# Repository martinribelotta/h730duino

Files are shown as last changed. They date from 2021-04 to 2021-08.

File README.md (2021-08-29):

# H730/733 Duino

Arduino form factor and software compatible board with giant cortex-m7 at 550MHz.

See test firmware [here](https://github.com/martinribelotta/h730duino-firmware)

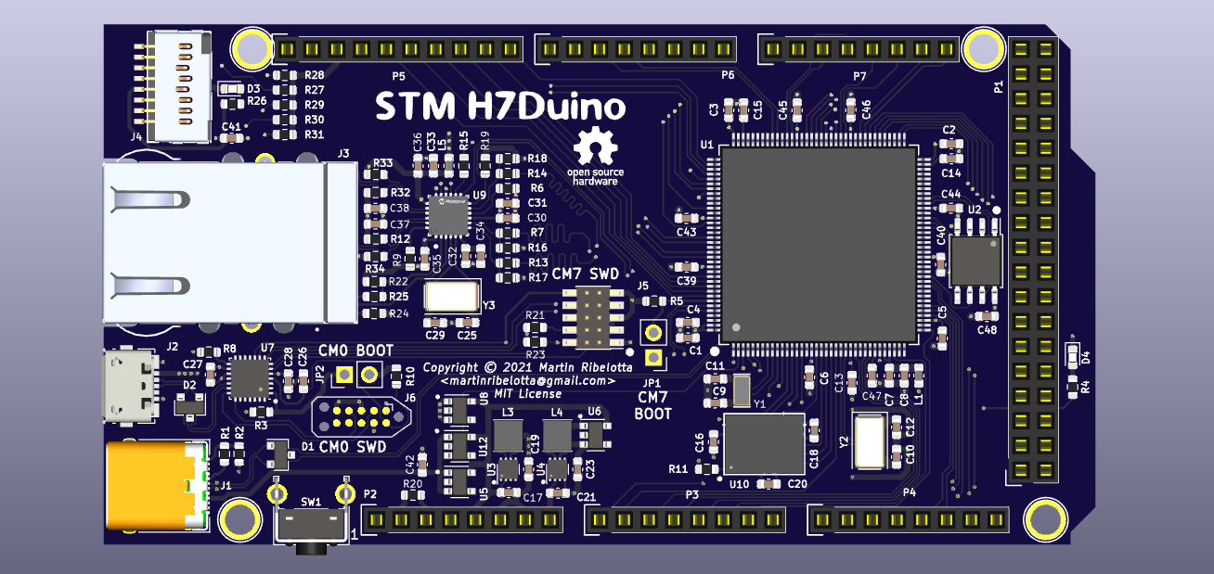
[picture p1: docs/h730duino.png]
banner


## Characteristics

- CPU Cortex-M7 at 550MHz.
- 128K/1 MB of internal flash (depending on the MCU version).
- 500 KB of internal RAM.
- 8 MB of external QSPI PSRAM at 133MHz SDR.
- 16/32/128 MB of external QSPI Flash at 133MHz SDR.
- 10/100Mb Ethernet.
- USB 2.0 OTG Type-C with power switch control.
- USB CMSIS-DAP Debugger.
- micro SD Card slot.
- Arduino Due/Mega compatible pin headers (3.3V IO, 5V tolerant on some pins).
- Arduino API compatible (via STM32Duino project).
- Micropython support.
- Protected power inputs with ideal diodes and DC-DC converter

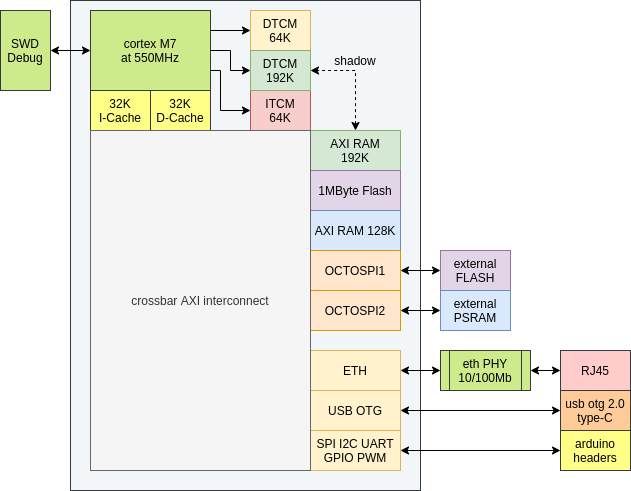
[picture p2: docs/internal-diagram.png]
internal diagram


## Capabilities and applications

Some interesting CPU capabilities are listed below:

- Hard real time capable CPU with predictable execution using tightly coupled memory for instruction and data.
- High speed and precision PWM suitable for motor control (BLDC, Stepper, DC).
- High resolution timing measure in capture mode for some pins.
- Arbitrary waveform generation in any GPIO using DMA without CPU intervention.
- High speed DACs suitable to generate analog signals up to 18MHz.
- Tow high speed 12 bits ADC suitable to capture up to 5MSPS in any channel.
- One high speed 16 bits ADC suitable to capture up to 7.5MSPSP
- Internal RAM with multiple block partitions enabling multiple peripheral access at same time without contention.
- External high density RAM up to 8 MB connected across 133MHz QSPI bus accessible in memory mapped mode or block device mode with on the fly encryption/decryption.
- External high density FLASH up to 16 MB connected across 133MHz QSPI bus accessible in memory mapped mode or block device mode with on the fly encryption/decryption.
- Multiplexed parallel memory controller for LCD and TFT access
- LCD interface with 666, 565 and 888 RGB with hsync/vsync and pixel clk (max 150MHz)
- Parallel capture port at 110MHz
- Parallel signal generation at 50MHz

These capabilities enable multiple interesting applications:

- High precision CNC and 3D printing.
- Signal generator and data acquisition system
- Human machine interface enabled terminal with USB, CAN and Ethernet support
- High speed logic analyzer.
- Programmable instrumentation system.
- Network laboratory instrument.

## Layout

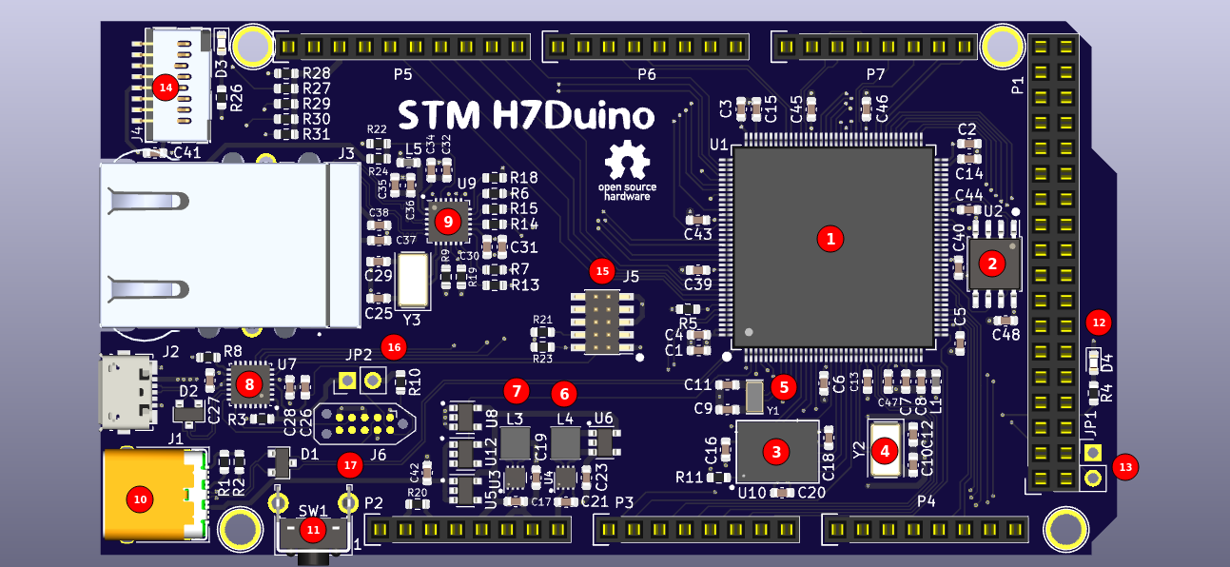
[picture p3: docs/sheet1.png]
layout


 1. MCU STM32H730/733/732
 2. QSPI flash (4/8/16/32MiB)
 3. HyperRAM (8MiB)
 4. 8MHz crystal
 5. 32.768KHz RTC crystal
 6. 5V in regulator
 7. 3.3V main regulator
 8. CMSIS-DAP debugger
 9. Ethernet PHY
 10. USB OTG Full Speed (connected to MCU)
 11. Reset button
 12. User LED
 13. STM32H7 BOOT jumper
 14. MicroSD connector
 15. SWD MCU connector
 16. CMSIS-DAP boot jumper
 17. CMSIS-DAP pogo pins for programming

## Schematics

[Download in PDF format](docs/schematic.pdf)

[Octopart BoM](https://octopart.com/bom-tool/nudLZO8C)

[CSV BoM (octpart compatible)](docs/stm32h7duino-v01.csv)






## License

[MIT License](LICENCE.tx)

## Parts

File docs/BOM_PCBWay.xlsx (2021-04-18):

 |  |  | xxxx xxxx xxxxx xxPCS BOM (Sample Bill of Materials)
Item # | *Designator | *Qty | Manufacturer | *Mfg Part # | Description / Value | *Package/Footprint | Type | Your Instructions / Notes
1 | C1 | 1 | Yageo | CC0603KRX5R5BB475 | Multilayer Ceramic Capacitor, CC Series, 4.7 - F, - 10%, X5R, 6.3 V, 0603 [1608 Metric] | SMD 0603 | SMD | Replaceable part number by equivalent
2 | C10,C12 | 2 | Yageo | CC0603CRNPO9BN1R0 | Surface Mount Ceramic Multilayer Capacitor 1pF 0.25pF C0G 50V 0603 Paper T/R | SMD 0603 | SMD | Replaceable part number by equivalent
3 | C13,C34 | 2 | Yageo | CC0603ZRY5V6BB105 | Surface Mount Ceramic Multilayer Capacitor 1uF -20% to 80% Y5V 10V 0603 Paper T/R | SMD 0603 | SMD | Replaceable part number by equivalent
4 | C14,C15,C42 | 3 | Yageo | CC0603ZRY5V6BB225 | Surface Mount Ceramic Multilayer Capacitor 2.2uF -20% to 80% Y5V 10V 0603 Paper T/R | SMD 0603 | SMD | Replaceable part number by equivalent
5 | C17,C21,C30,C36 | 4 | KEMET | C0603C106M8PACTU | Cap Ceramic 10uF 10V X5R 20% SMD 0603 85°C Paper T/R | SMD 0603 | SMD | Replaceable part number by equivalent
6 | C19,C23 | 2 | Murata | GRM187R61A226ME15D | 0603 22 uF 10 V ±20% Tolerance X5R Multilayer Ceramic Capacitor | SMD 0603 | SMD | Replaceable part number by equivalent
7 | C2,C3,C4,C5,C6,C7,C16,C18,C20,C26,C27,C28,C31,C33,C35,C39,C40,C41,C43,C44,C45,C46,C47,C48 | 24 | Yageo | CC0603KRX7R9BB104 | Multilayer Ceramic Capacitor, CC Series, 0.1 - F, - 10%, X7R, 50 V, 0603 [1608 Metric] | SMD 0603 | SMD | Replaceable part number by equivalent
8 | C32 | 1 | AVX | 06035C471KAT2A | 0603 470 pF 50V ±10 % Tolerance X7R Surface Mount Multilayer Ceramic Capacitor | SMD 0603 | SMD | Replaceable part number by equivalent
9 | C37,C38 | 2 | AVX | 06035C223KAT2A | 0603 22nF 50V ±10 % Tolerance X7R Surface Mount Multilayer Ceramic Capacitor | SMD 0603 | SMD | Replaceable part number by equivalent
10 | C8,C9,C11,C25,C29 | 5 | Yageo | CC0603JRNPO9BN100 | Surface Mount Ceramic Multilayer Capacitor 10pF 5% C0G 50V 0603 Paper T/R | SMD 0603 | SMD | Replaceable part number by equivalent
11 | D1,D2 | 2 | Littelfuse | SP0502BAHTG | SP050xBA Series 8.5 V 30 pF Dual Uni-Directional TVS Avalanche Diode - SOT-23-5 | SOT-23-5 | SMD
12 | D3,D4 | 2 | Osram Opto | LS Q976-NR-1 | LED Uni-Color Super Red 645nm 2-Pin Chip 0603(1608Metric) T/R | SMD 0603 | SMD | Replaceable part number by equivalent
13 | J1 | 1 | Amphenol | 12401610E4#2A | Conn USB Type C RCP 24 POS 0.5mm Solder RA SMD 24 Terminal 1 Port Automotive | USB_C_Receptacle_Amphenol_12401610E4-2A | SMD
14 | J2 | 1 | Molex | 47346-0001 | Micro-USB B Receptacle with Flange, Bottom Mount, Surface Mount, Lead-Free | USB_Micro-B_Molex_47346-0001 | SMD
15 | J3 | 1 | Bel Fuse | L834-1G1T-91 | Conn RJ45 F 8 POS 1.02mm Solder RA Through Hole 16 Terminal 1 Port Tray | RJ45 BEL_L834-1G1T-91 | Thru-home
16 | J4 | 1 | Molex | 105162-0001 | Conn Micro SD Card HDR 8 POS 1.09mm Solder RA SMD 0.5A/Contact Embossed T/R | SD Card slot 105162-0001 | SMD
17 | L1,L5 | 2 | Taiyo Yuden | BK1608HS220-T | Ferrite Beads Multi-Layer 22Ohm 25% 100MHz 1.5A 0.05Ohm DCR 0603 T/R | SMD 0603 | SMD | Replaceable part number by equivalent
18 | L3,L4 | 2 | Taiyo Yuden | NR3015T2R2M | Inductor Power Shielded Wirewound 2.2uH 20% 100KHz Ferrite 1.5A 0.072Ohm DCR 1212 T/R | Nonstandard | SMD
19 | P1 | 1 | Oupiin | 2044-2X18G00SA | Pcb Socket, Double Row, 36 Pin, | Pin Socket 2x18 | Thru-home | Replaceable part number by equivalent
20 | P2,P3,P4,P6,P7 | 5 | Oupiin | 2044-1X08G00SA | Pcb Socket, Single Row, 8 Pin, S | Pin Socket 1x8 | Thru-home | Replaceable part number by equivalent
21 | P5 | 1 | Oupiin | 2044-1X10G00SA | Pcb Socket, Single Row, 10 Pin, | Pin Socket 1x10 | Thru-home | Replaceable part number by equivalent
22 | R1,R2,R4,R19,R26 | 5 | Yageo | RC0603JR-071K5L | Res Thick Film 0603 1.5K Ohm 5% 0.1W(1/10W) ±100ppm/°C Pad SMD T/R | SMD 0603 | SMD | Replaceable part number by equivalent
23 | R12,R32,R33,R34 | 4 | Yageo | RC0603FR-0749R9L | Res General Purpose Thick Film 0603 49.9 Ohm 1% 1/10W ±100ppm/°C Molded SMD Paper T/R | SMD 0603 | SMD | Replaceable part number by equivalent
24 | R24,R25 | 2 | Yageo | RC0603JR-07220RL | Res Thick Film 0603 220 Ohm 5% 1/10W +/-100ppm/ßC Molded SMD Paper T/R | SMD 0603 | SMD | Replaceable part number by equivalent
25 | R3,R5,R6,R7,R8,R10,R11,R13,R14,R15,R16,R17,R18,R20,R21,R22,R23,R27,R28,R29,R30,R31 | 22 | Yageo | RC0603FR-0710KL | Res General Purpose Thick Film 0603 10K Ohm 1% 1/10W ±100ppm/°C Molded SMD Paper T/R | SMD 0603 | SMD | Replaceable part number by equivalent
26 | R9 | 1 | Yageo | RT0603BRD0712K1L | High Precision-High Stability Chip Resistor Thin Film 0603 12.1kOhm 0.1% Paper T/R | SMD 0603 | SMD | Replaceable part number by equivalent
27 | SW1 | 1 | C&K Components | PTS645VL58-2 LFS | Switch Tactile N.O SPST Round Button PC Pins 0.05A 12VDC 100000Cycle 1.27N Thru-Hole Bulk | Switch Rigth Angle SPST | Thru-home
28 | U1 | 1 | STMicroelectronics | STM32H730ZBT6 | MCU 32-bit ARM Cortex M7 RISC 128KB Flash 1.8V/2.5V/3.3V 144-Pin LQFP Tray | LQFP144 | SMD
29 | U10 | 1 | Cypress Semiconductor | S27KL0641DABHI020 | HyperBus Memory, 64 Mbit Density, 40 ns Initial Access Time, 200 MBps Interface Bandwidth, FBGA-24, RoHS | FBGA-24 | SMD
30 | U12 | 1 | Diodes Inc. | AP2161WG-7 | AP2161 Series 115 mOhm 1.5 A Single Channel Current-Limited Power Switch- SOT-25 | SC-74A | SMD
31 | U2 | 1 | ISSI | IS25LP032D-JBLE | NOR Flash Serial (SPI, Dual SPI, Quad SPI) 2.5V/3.3V 32M-bit 4M x 8 8ns 8-Pin SOIC Bulk/T/R | 8-SOIC 5.30mm Width | SMD
32 | U3 | 1 | Texas Instruments | TPS62162DSGT | Conv DC-DC 3V to 17V Synchronous Step Down Single-Out 3.3V 1A 8-Pin WSON EP T/R | WSON-8 | SMD
33 | U4 | 1 | Texas Instruments | TPS62163DSGT | Conv DC-DC 3V to 17V Synchronous Step Down Single-Out 5V 1A 8-Pin WSON EP T/R | WSON-8 | SMD
34 | U5,U6,U8 | 3 | Maxim Integrated | MAX40200AUK+T | MAX40200AUK Seires 5.5 V 1 A MicropowerCurrent Switch Diode - SOT23-5 | SOT-23-5 | SMD
35 | U7 | 1 | STMicroelectronics | STM32F048G6U6 | MCU 32-Bit STM32F ARM Cortex M0 RISC 32KB Flash 1.8V/2.5V/3.3V 28-Pin UFQFPN Tray | UFQFPN-28 | SMD
36 | U9 | 1 | Microchip | LAN8742A-CZ | Small Footprint RMII 10/100 Ethernet Transceiver with flexPWR Technology | SQFN-24 | SMD
37 | Y1 | 1 | Citizen Finetech Miyota | VMK3-9005-32K7680000 | Crystal 0.032768MHz ±20ppm (Tol) 12.5pF Flexural 70000Ohm 2-Pin CSMD T/R | 2-SMD 3.2x1.5mm | SMD
38 | Y2 | 1 | Abracon | ABM7-8.000MHZ-D2Y-T | Crystal 8MHz ±20ppm (Tol) ±30ppm (Stability) 18pF FUND 100Ohm 2-Pin Mini-CSMD T/R | 2-SMD 6x3.5mm | SMD
39 | Y3 | 1 | Abracon | ABM7-25.000MHZ-D2Y-T | Crystal 25MHz ±20ppm (Tol) ±30ppm (Stability) 18pF FUND 50Ohm 2-Pin Mini-CSMD T/R | 2-SMD 6x3.5mm | SMD
Need a quick and accurante quote? Need an efficient production? Please read SMT Ordering Necessary Files & Info in 1 minute. Thank you very much! (https://www.pcbway.com/smt_ordering_guide.html)
Click for Instructions on How to Create a BOM (https://www.pcbway.com/blog/PCB_Assembly/How_to_Build_a_BOM__Bill_Of_Materials_.html)

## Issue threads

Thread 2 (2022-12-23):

Available for purchase?

JacobChrist, 2022-12-23:
Do you have any of these boards assembled that can be purchased somewhere?

martinribelotta, 2022-12-23:
Not at this point due the shortage...

I maintain this issue open while this condition not change

JacobChrist, 2022-12-24:
Has this board been built and tested?

https://www.pcbway.com/project/shareproject/stm32h7duino.html

Or if I purchased it would I be troubleshooting it if I built it myself?

martinribelotta, 2022-12-24:
The board have many ussues corrected but not tested:

 [x] The debuger is removed due to lack of the stm32f042 in the market
 [x] The OctoSPI route is corrected but not tested
 [x] the QSPI is not work but apperar as a firmware problem and not hardware connection
 [x] ethernet is not tested
 [x] USB is working in firmware and bootloader mode
 [x] CPU is working
 [x] RTC not start properly. Need more investigation

JacobChrist, 2022-12-28:
So I've been looking at the schematic and there is something that is confusing to me.  It may be correct but I have little experience with QSPI and none with OCTO SPI.  The OSPI chip is split between two different SPI ports.

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

Why not use P1 IO0-IO7 on this part?

This is from this part of the schematic:

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

JacobChrist, 2023-01-12:
I've done a lot of reading on OCTOSPI today as well as trying to settle on where to hookup memory to my H730 and I'm pretty sure that your OCTOSPI lines are hooked up incorrectly on your memory. (Assuming I"m looking at the latest schematic).   I don't fully understand if it is better to use the upper or lower nibble for the QSPI device but it seems like you should use all the P1 on the RAM chip and all of the P2 pins on the FLASH chip.

JacobChrist, 2023-01-12:
The SEEED Studio WIO board uses P2-IO4..7 for flash.

https://www.seeedstudio.com/Wio-Lite-AI-Single-Board-p-5120.html

JacobChrist, 2023-01-12:
Today I started playing around with STM32 CUBE MX IDE and I can now see that it is quite easy to move the data nibbles of either P1 or P2 to either bus, so I now can see that your wiring probably will work as is.

JacobChrist, 2023-10-05:
@martinribelotta any progress on this design / production boards?

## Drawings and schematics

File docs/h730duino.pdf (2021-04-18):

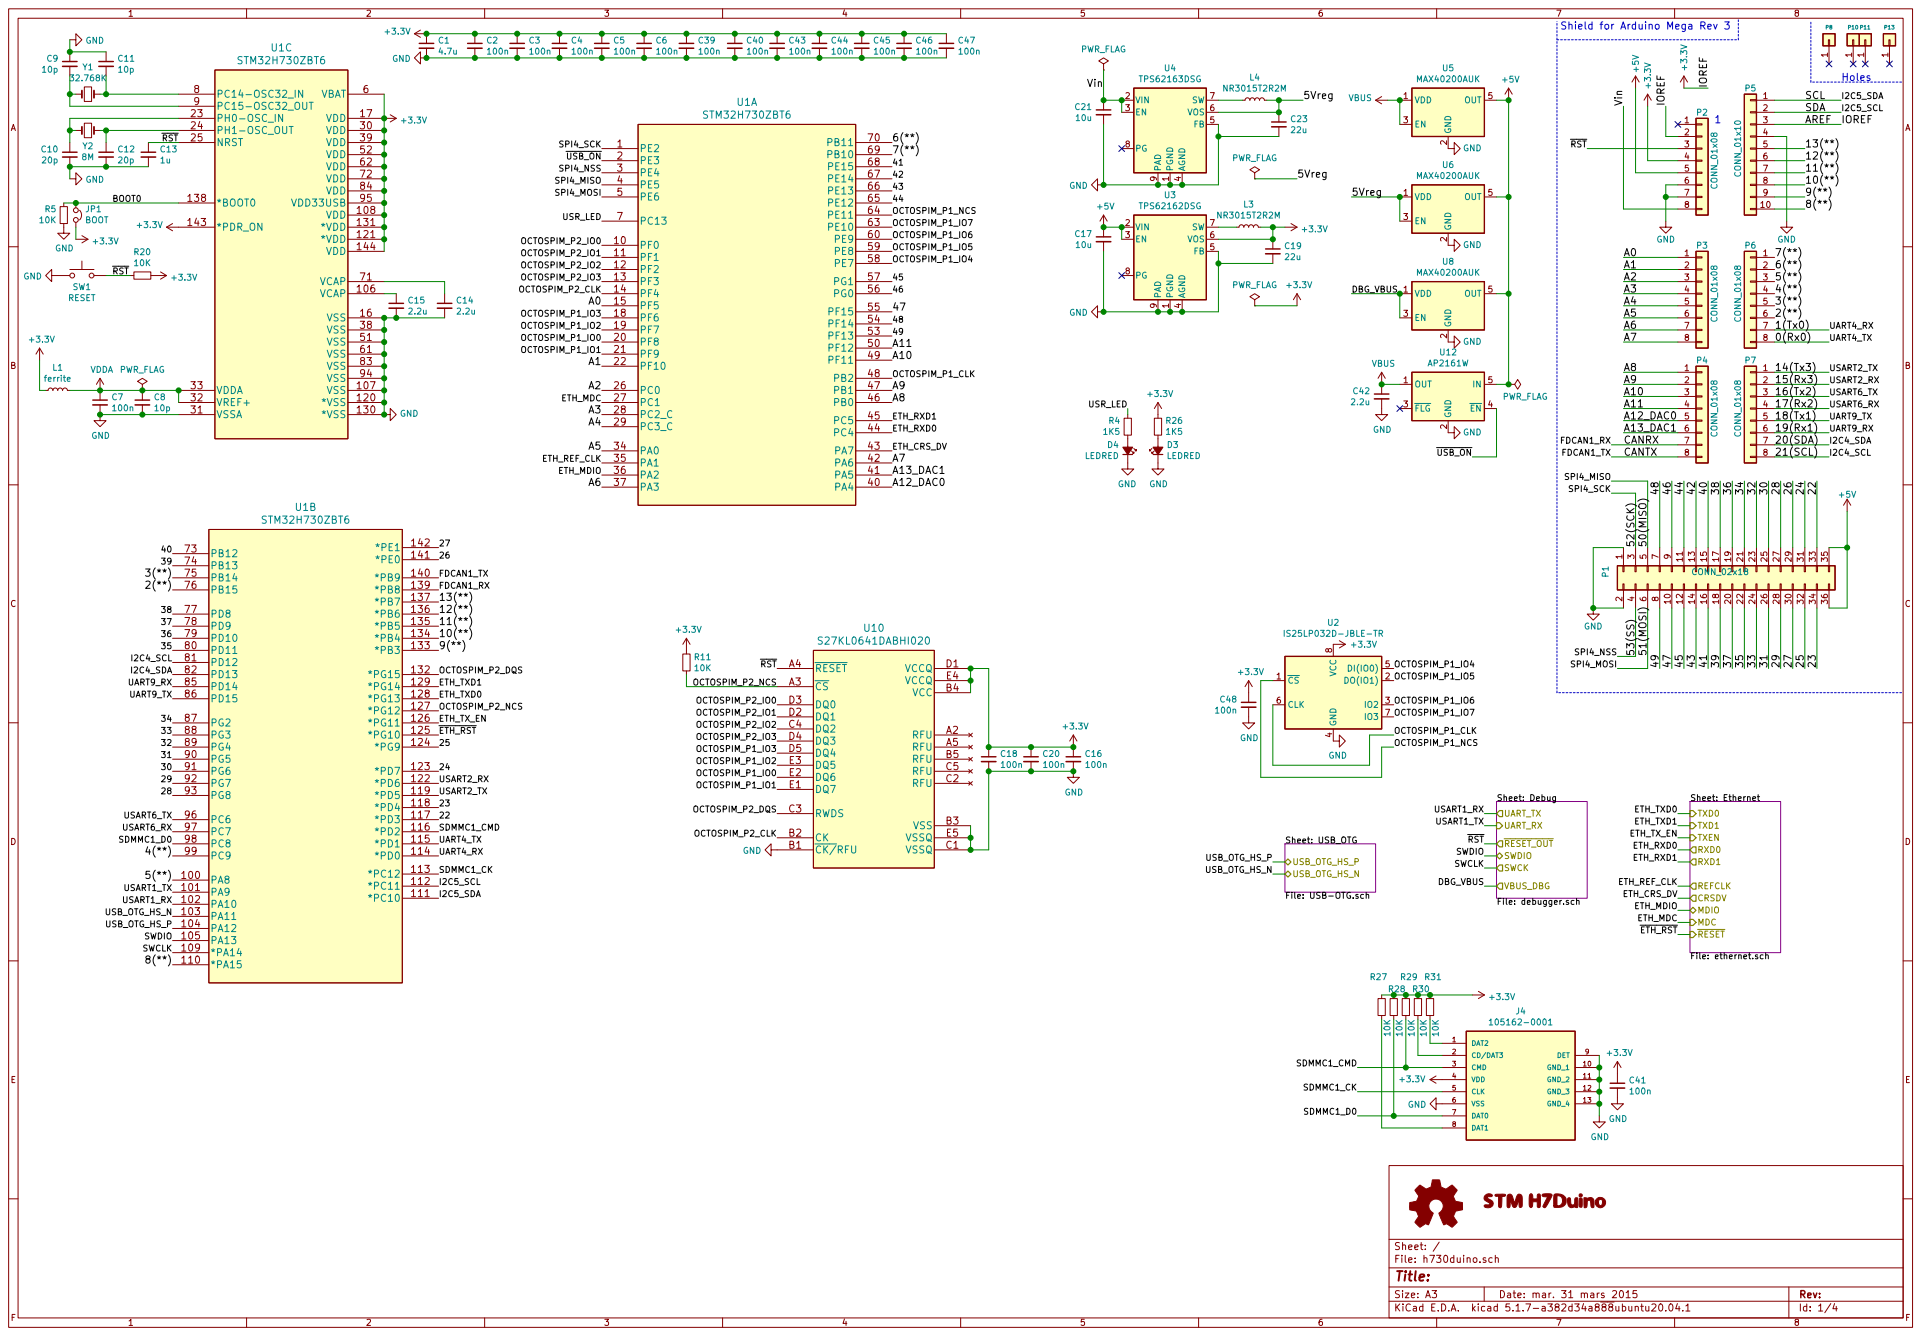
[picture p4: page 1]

4 FB 5 VOS 6 SW 7 PG 8 PAD

Sheet: Ethernet File: ethernet.sch TXD0 TXD1 TXEN
RXD0 RXD1 CRSDV MDIO MDC

SWDIO
File: debugger.sch SWCK

File: USB-OTG.sch USB_OTG_HS_P USB_OTG_HS_N

Id: 1/4 Title: File: h730duino.sch Sheet: /

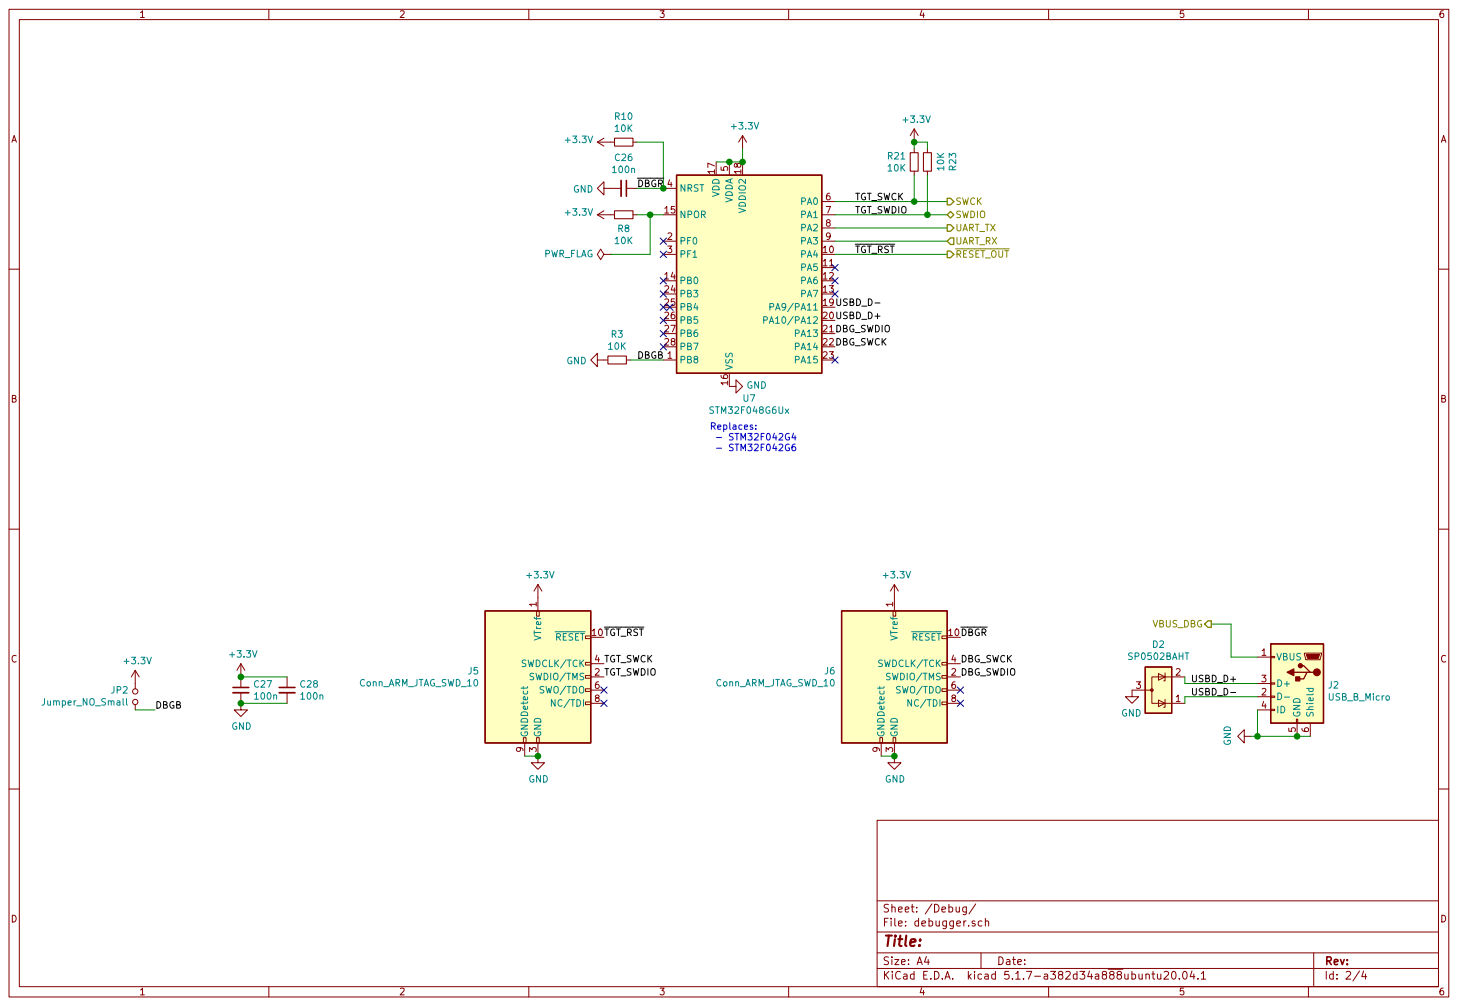
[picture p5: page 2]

3 SWDCLK/TCK 4 SWO/TDO 6 NC/TDI 8 GNDDetect 9
J6 Conn_ARM_JTAG_SWD_10 GND

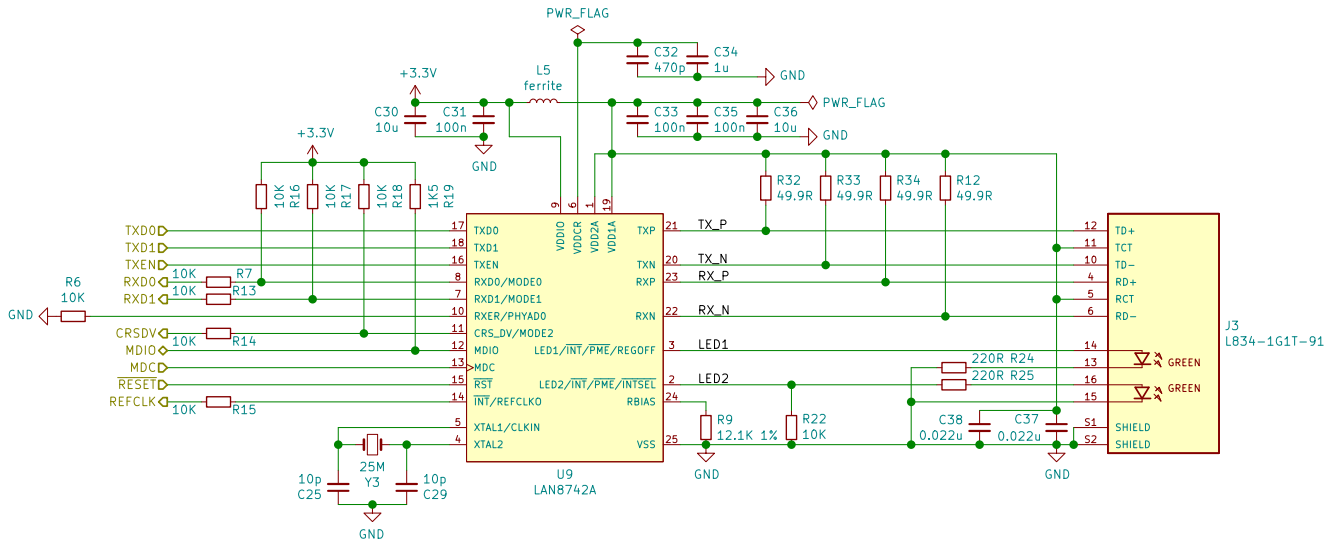
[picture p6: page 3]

14
13

Id: 3/4 Title: File: ethernet.sch Sheet: /Ethernet/

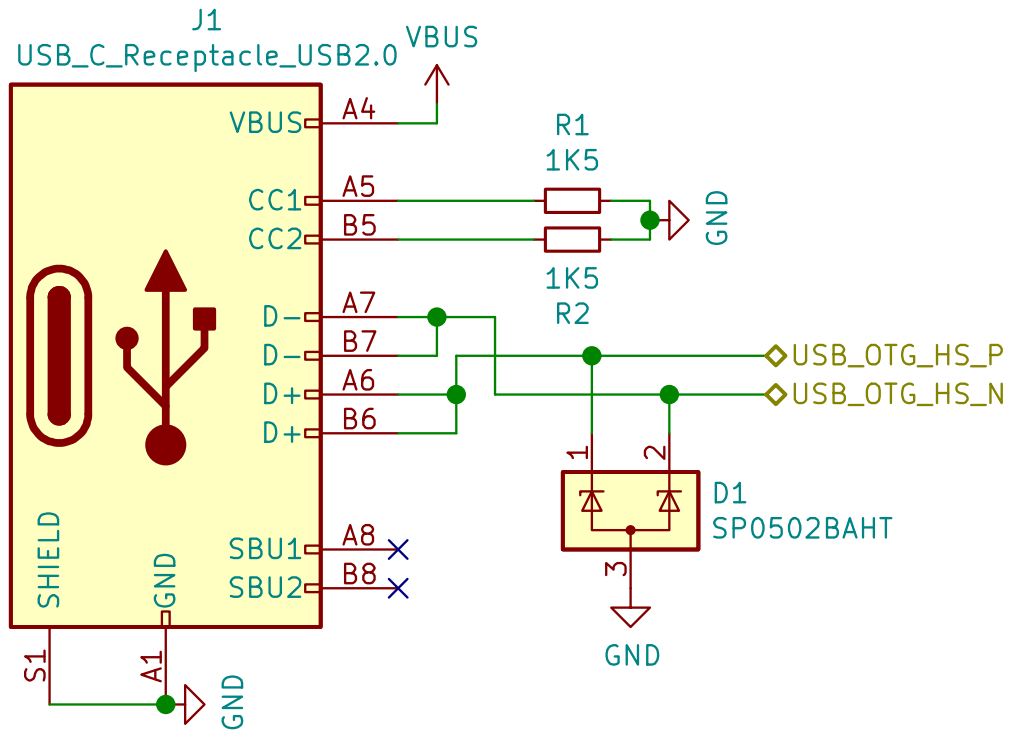
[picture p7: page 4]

Id: 4/4 Title: File: USB-OTG.sch Sheet: /USB_OTG/

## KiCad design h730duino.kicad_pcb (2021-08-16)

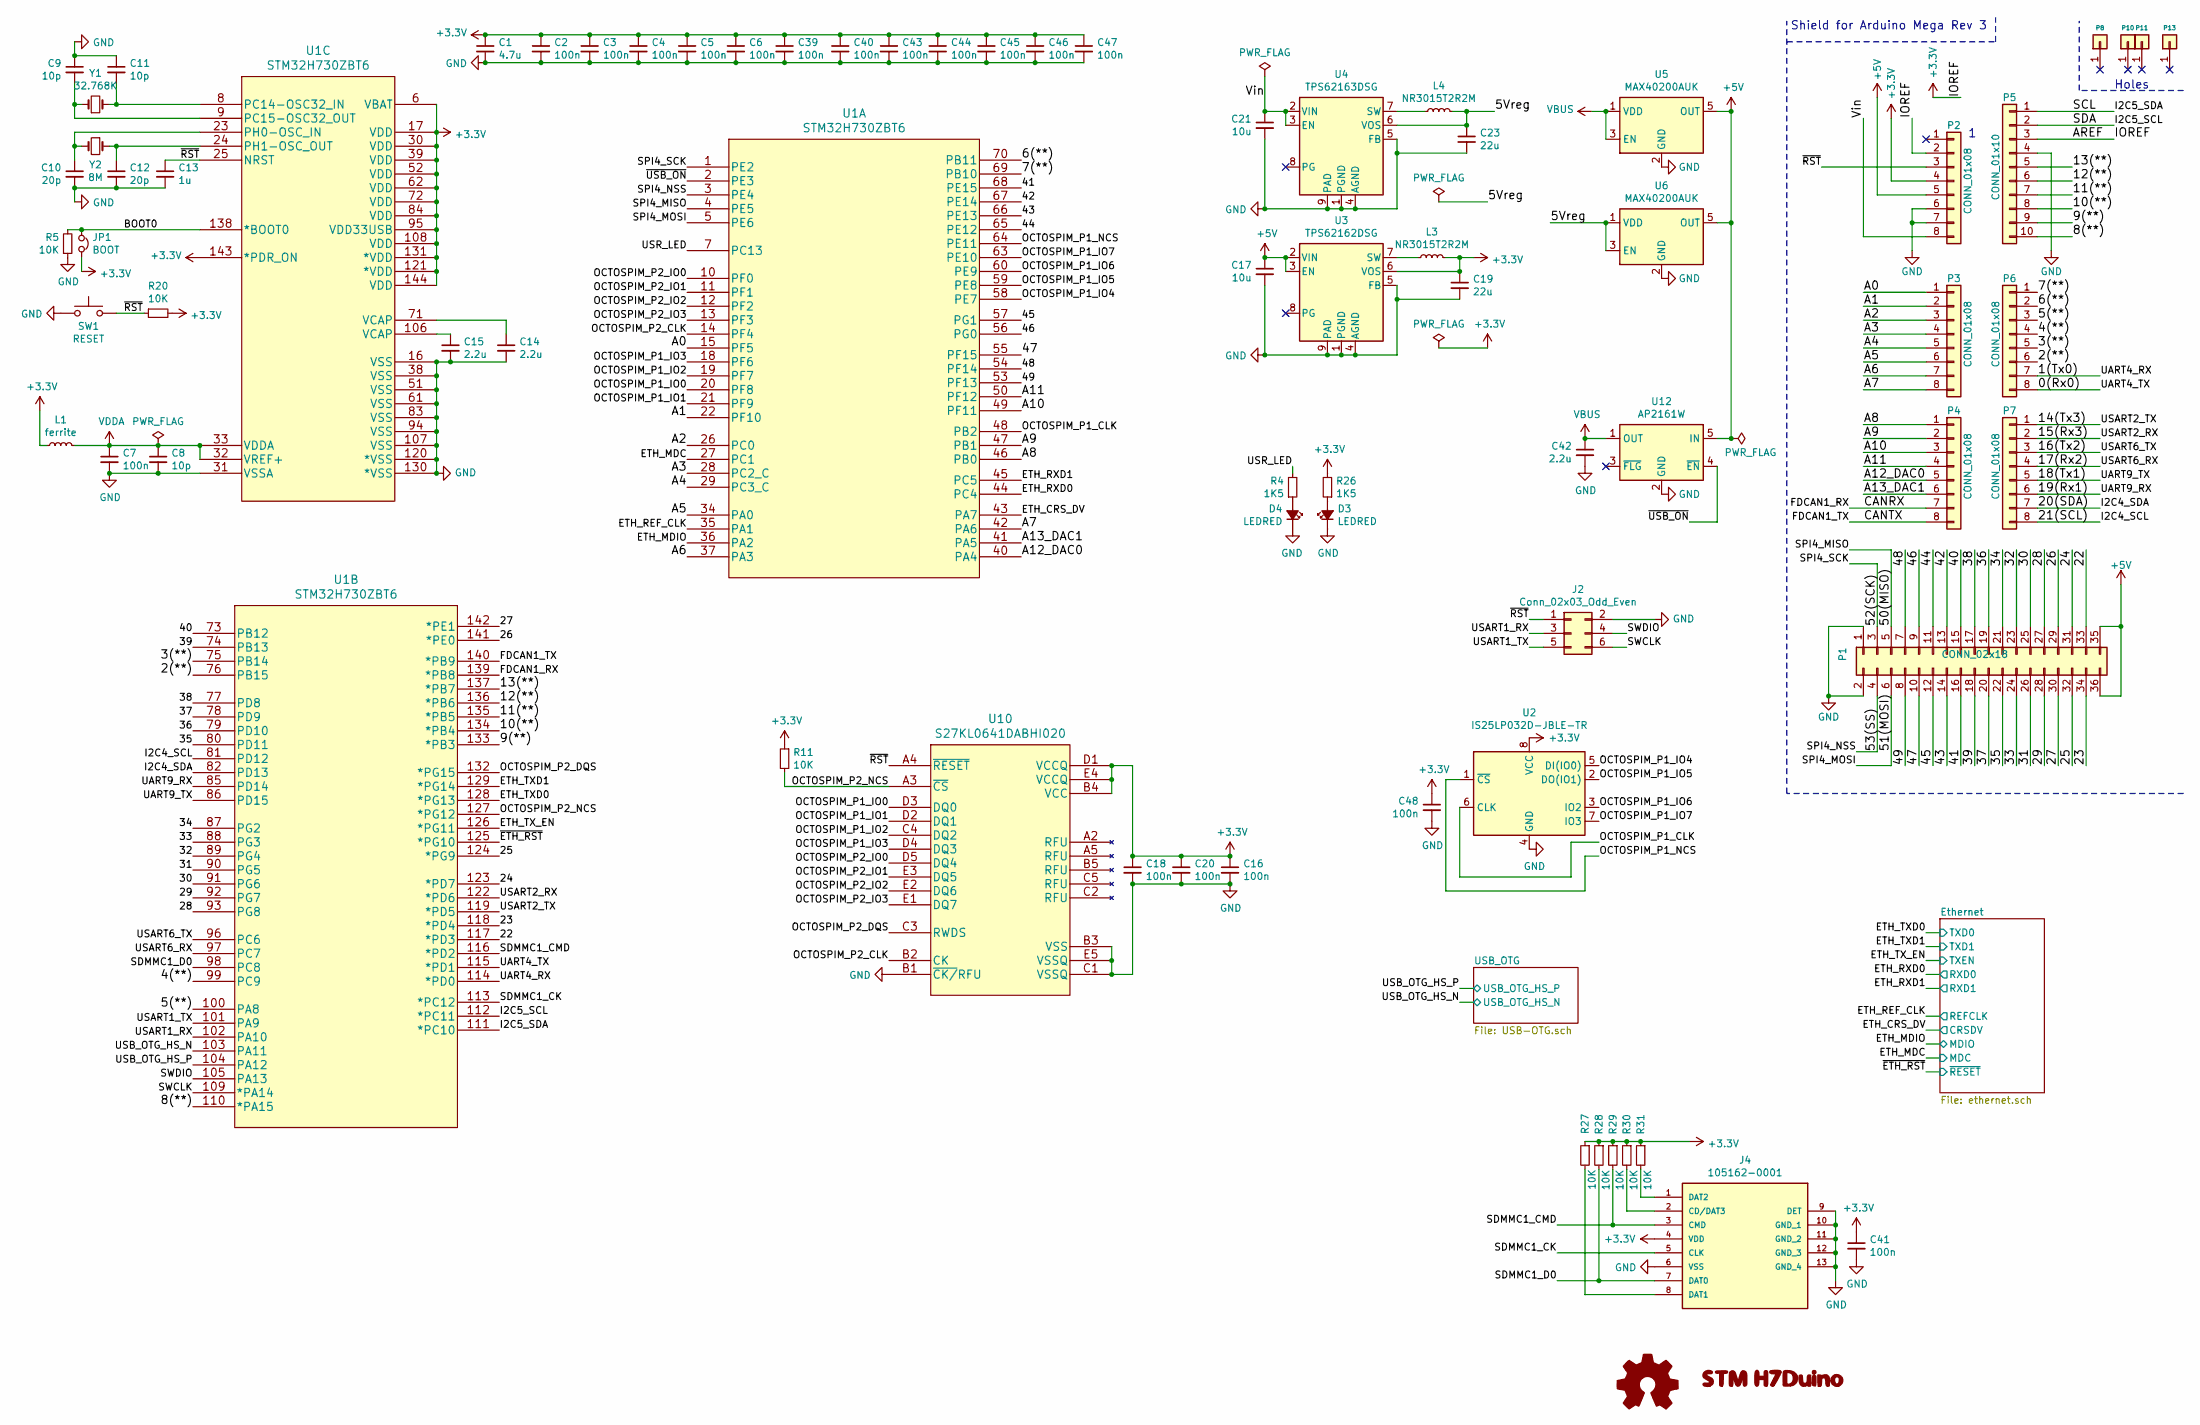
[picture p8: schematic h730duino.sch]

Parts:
C1: 4.7u; C_0603_1608Metric; MANUFACTURER_PART_NUMBER CC0603KRX5R5BB475
C2, C3, C4, C5, C6, C7, C16, C18, C20, C39, C40, C41, C43, C44, C45, C46, C47, C48: 100n; C_0603_1608Metric; MANUFACTURER_PART_NUMBER CC0603KRX7R9BB104
C8, C9, C11: 10p; C_0603_1608Metric; MANUFACTURER_PART_NUMBER CC0603JRNPO9BN100
C10, C12: 20p; C_0603_1608Metric; MANUFACTURER_PART_NUMBER CC0603CRNPO9BN1R0
C13: 1u; C_0603_1608Metric; MANUFACTURER_PART_NUMBER CC0603ZRY5V6BB105
C14, C15, C42: 2.2u; C_0603_1608Metric; MANUFACTURER_PART_NUMBER CC0603ZRY5V6BB225
C17, C21: 10u; C_0603_1608Metric; MANUFACTURER_PART_NUMBER 0603ZD106KAT2A
C19, C23: 22u; C_0603_1608Metric; MANUFACTURER_PART_NUMBER GRM188R61A226ME15D
D3, D4: LEDRED; LED_0603_1608Metric; MANUFACTURER_PART_NUMBER LS Q976-NR-1
G1: LOGO; logo
J2: Conn_02x03_Odd_Even; PinHeader_2x03_P2.54mm_Horizontal
J4: 105162-0001; MANUFACTURER_PART_NUMBER 105162-0001; MOUSER_PART_NUMBER 538-105162-0001
JP1: BOOT; PinHeader_1x02_P2.54mm_Vertical
L1: ferrite; L_0603_1608Metric; MANUFACTURER_PART_NUMBER BK1608HS220-T
L3, L4: NR3015T2R2M; L_Taiyo-Yuden_MD-3030; MANUFACTURER_PART_NUMBER NR3015T2R2M
LOGO1: Logo_Open_Hardware_Small; OSHW-Logo_7.5x8mm_SilkScreen
P1: CONN_02x18; Socket_Strip_Arduino_2x18; MANUFACTURER_PART_NUMBER 2044-2X18G00SA
P2, P3, P4, P6, P7: CONN_01x08; Socket_Strip_Arduino_1x08; MANUFACTURER_PART_NUMBER 2044-1X08G00SA
P5: CONN_01x10; Socket_Strip_Arduino_1x10; MANUFACTURER_PART_NUMBER 2044-1X10G00SA
P8, P10, P11, P13: CONN_01X01; Arduino_1pin
R4, R26: 1K5; R_0603_1608Metric; MANUFACTURER_PART_NUMBER RC0603JR-071K5L
R5, R11, R20, R27, R28, R29, R30, R31: 10K; R_0603_1608Metric; MANUFACTURER_PART_NUMBER RC0603FR-0710KL
SW1: RESET; SW_Tactile_SPST_Angled_PTS645Vx39-2LFS; MANUFACTURER_PART_NUMBER PTS645VL58-2 LFS
U1: STM32H730ZBT6; MANUFACTURER_PART_NUMBER STM32H730ZBT6
U2: IS25LP032D-JBLE-TR; SOIC-8_5.23x5.23mm_P1.27mm; MANUFACTURER_PART_NUMBER IS25LP032D-JBLE-TR
U3: TPS62162DSG; WSON-8-1EP_2x2mm_P0.5mm_EP0.9x1.6mm_ThermalVias; MANUFACTURER_PART_NUMBER TPS62162DSG
U4: TPS62163DSG; WSON-8-1EP_2x2mm_P0.5mm_EP0.9x1.6mm_ThermalVias; MANUFACTURER_PART_NUMBER TPS62163DSG
U5, U6: MAX40200AUK; SOT-23-5; MANUFACTURER_PART_NUMBER MAX40200AUK
U10: S27KL0641DABHI020; MANUFACTURER_PART_NUMBER S27KL0641DABHI020
U12: AP2161W; SOT-23-5; MANUFACTURER_PART_NUMBER AP2161W
Y1: 32.768K; Crystal_SMD_3215-2Pin_3.2x1.5mm; MANUFACTURER_PART_NUMBER CM315D32768DZFT
Y2: 8M; Crystal_SMD_5032-2Pin_5.0x3.2mm; MANUFACTURER_PART_NUMBER ABM7-8.000MHZ-D2Y-T

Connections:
+3V3: C1.1, C2.1, C3.1, C4.1, C5.1, C6.1, C16.1, C18.1, C19.1, C20.1, C39.1, C40.1, C41.1, C43.1, C44.1, C45.1, C46.1, C47.1, C48.1, J4.4 (VDD), JP1.1, L1.1, L3.2, P2.2, P2.4, P5.3, R11.1, R20.2, R26.2, R27.1, R28.1, R29.1, R30.1, R31.1, U1.6 (VBAT), U1.17 (VDD), U1.30 (VDD), U1.39 (VDD), U1.52 (VDD), U1.62 (VDD), U1.72 (VDD), U1.84 (VDD), U1.95 (VDD33USB), U1.108 (VDD), U1.121 (*VDD), U1.131 (*VDD), U1.143 (*PDR_ON), U1.144 (VDD), U2.8 (VCC), U3.6 (VOS), U10.B4 (VCC), U10.D1 (VCCQ), U10.E4 (VCCQ); also elsewhere on the board
+5V: C17.1, P1.35, P1.36, P2.5, U3.2 (VIN), U3.3 (EN), U5.5 (OUT), U6.5 (OUT), U12.5 (IN)
/0(Rx0): P6.8, U1.115 (*PD1)
/1(Tx0): P6.7, U1.114 (*PD0)
/2(**): P6.6, U1.76 (PB15)
/3(**): P6.5, U1.75 (PB14)
/4(**): P6.4, U1.99 (PC9)
/5(**): P6.3, U1.100 (PA8)
/5Vreg: C23.1, L4.2, U4.6 (VOS), U6.1 (VDD), U6.3 (EN)
/6(**): P6.2, U1.70 (PB11)
/7(**): P6.1, U1.69 (PB10)
/8(**): P5.10, U1.110 (*PA15)
/9(**): P5.9, U1.133 (*PB3)
/10(**): P5.8, U1.134 (*PB4)
/11(**): P5.7, U1.135 (*PB5)
/12(**): P5.6, U1.136 (*PB6)
/13(**): P5.5, U1.137 (*PB7)
/14(Tx3): P7.1, U1.119 (*PD5)
/15(Rx3): P7.2, U1.122 (*PD6)
/16(Tx2): P7.3, U1.96 (PC6)
/17(Rx2): P7.4, U1.97 (PC7)
/18(Tx1): P7.5, U1.86 (PD15)
/19(Rx1): P7.6, U1.85 (PD14)
/20(SDA): P7.7, U1.82 (PD13)
/21(SCL): P7.8, U1.81 (PD12)
/22: P1.33, U1.117 (*PD3)
/23: P1.34, U1.118 (*PD4)
/24: P1.31, U1.123 (*PD7)
/25: P1.32, U1.124 (*PG9)
/26: P1.29, U1.141 (*PE0)
/27: P1.30, U1.142 (*PE1)
/28: P1.27, U1.93 (PG8)
/29: P1.28, U1.92 (PG7)
/30: P1.25, U1.91 (PG6)
/31: P1.26, U1.90 (PG5)
/32: P1.23, U1.89 (PG4)
/33: P1.24, U1.88 (PG3)
/34: P1.21, U1.87 (PG2)
/35: P1.22, U1.80 (PD11)
/36: P1.19, U1.79 (PD10)
/37: P1.20, U1.78 (PD9)
/38: P1.17, U1.77 (PD8)
/39: P1.18, U1.74 (PB13)
/40: P1.15, U1.73 (PB12)
/41: P1.16, U1.68 (PE15)
/42: P1.13, U1.67 (PE14)
/43: P1.14, U1.66 (PE13)
/44: P1.11, U1.65 (PE12)
/45: P1.12, U1.57 (PG1)
/46: P1.9, U1.56 (PG0)
/47: P1.10, U1.55 (PF15)
/48: P1.7, U1.54 (PF14)
/49: P1.8, U1.53 (PF13)
/50(MISO): P1.5, U1.4 (PE5)
/51(MOSI): P1.6, U1.5 (PE6)
/52(SCK): P1.3, U1.1 (PE2)
/53(SS): P1.4, U1.3 (PE4)
/A0: P3.1, U1.15 (PF5)
/A1: P3.2, U1.22 (PF10)
/A2: P3.3, U1.26 (PC0)
/A3: P3.4, U1.28 (PC2_C)
/A4: P3.5, U1.29 (PC3_C)
/A5: P3.6, U1.34 (PA0)
/A6: P3.7, U1.37 (PA3)
/A7: P3.8, U1.42 (PA6)
/A8: P4.1, U1.46 (PB0)
/A9: P4.2, U1.47 (PB1)
/A10: P4.3, U1.49 (PF11)
/A11: P4.4, U1.50 (PF12)
/A12_DAC0: P4.5, U1.40 (PA4)
/A13_DAC1: P4.6, U1.41 (PA5)
/BOOT0: JP1.2, R5.2, U1.138 (*BOOT0)
/CANRX: P4.7, U1.139 (*PB8)
/CANTX: P4.8, U1.140 (*PB9)
/ETH_CRS_DV: U1.43 (PA7); also elsewhere on the board
/ETH_MDC: U1.27 (PC1); also elsewhere on the board
/ETH_MDIO: U1.36 (PA2); also elsewhere on the board
/ETH_REF_CLK: U1.35 (PA1); also elsewhere on the board
/ETH_RXD0: U1.44 (PC4); also elsewhere on the board
/ETH_RXD1: U1.45 (PC5); also elsewhere on the board
/ETH_TXD0: U1.128 (*PG13); also elsewhere on the board
/ETH_TXD1: U1.129 (*PG14); also elsewhere on the board
/ETH_TX_EN: U1.126 (*PG11); also elsewhere on the board
/I2C5_SCL: P5.2, U1.112 (*PC11)
/I2C5_SDA: P5.1, U1.111 (*PC10)
/OCTOSPIM_P1_CLK: U1.48 (PB2), U2.6 (CLK)
/OCTOSPIM_P1_IO0: U1.20 (PF8), U10.D3 (DQ0)
/OCTOSPIM_P1_IO1: U1.21 (PF9), U10.D2 (DQ1)
/OCTOSPIM_P1_IO2: U1.19 (PF7), U10.C4 (DQ2)
/OCTOSPIM_P1_IO3: U1.18 (PF6), U10.D4 (DQ3)
/OCTOSPIM_P1_IO4: U1.58 (PE7), U2.5 (DI(IO0))
/OCTOSPIM_P1_IO5: U1.59 (PE8), U2.2 (DO(IO1))
/OCTOSPIM_P1_IO6: U1.60 (PE9), U2.3 (IO2)
/OCTOSPIM_P1_IO7: U1.63 (PE10), U2.7 (IO3)
/OCTOSPIM_P1_NCS: U1.64 (PE11), U2.1 (~CS)
/OCTOSPIM_P2_CLK: U1.14 (PF4), U10.B2 (CK)
/OCTOSPIM_P2_DQS: U1.132 (*PG15), U10.C3 (RWDS)
/OCTOSPIM_P2_IO0: U1.10 (PF0), U10.D5 (DQ4)
/OCTOSPIM_P2_IO1: U1.11 (PF1), U10.E3 (DQ5)
/OCTOSPIM_P2_IO2: U1.12 (PF2), U10.E2 (DQ6)
/OCTOSPIM_P2_IO3: U1.13 (PF3), U10.E1 (DQ7)
/OCTOSPIM_P2_NCS: R11.2, U1.127 (*PG12), U10.A3 (~CS)
/SDMMC1_CK: J4.5 (CLK), U1.113 (*PC12)
/SDMMC1_CMD: J4.3 (CMD), R29.2, U1.116 (*PD2)
/SDMMC1_D0: J4.7 (DAT0), R28.2, U1.98 (PC8)
/SWCLK: J2.6, U1.109 (*PA14)
/SWDIO: J2.4, U1.105 (PA13)
/USART1_RX: J2.3, U1.102 (PA10)
/USART1_TX: J2.5, U1.101 (PA9)
/USB_OTG_HS_N: U1.103 (PA11); also elsewhere on the board
/USB_OTG_HS_P: U1.104 (PA12); also elsewhere on the board
/USR_LED: R4.2, U1.7 (PC13)
/Vin: C21.1, P2.8, U4.2 (VIN), U4.3 (EN)
/~ETH_RST: U1.125 (*PG10); also elsewhere on the board
/~RST: C13.1, J2.1, P2.3, R20.1, SW1.1, U1.25 (NRST), U10.A4 (~RESET)
/~USB_ON: U1.2 (PE3), U12.4 (~EN)
GND: C1.2, C2.2, C3.2, C4.2, C5.2, C6.2, C7.2, C8.2, C9.1, C10.2, C11.1, C12.2, C13.2, C14.2, C15.2, C16.2, C17.2, C18.2, C19.2, C20.2, C21.2, C23.2, C39.2, C40.2, C41.2, C42.2, C43.2, C44.2, C45.2, C46.2, C47.2, C48.2, D3.1 (K), D4.1 (K), J2.2, J4.6 (VSS), J4.9 (DET), J4.10 (GND_1), J4.11 (GND_2), J4.12 (GND_3), J4.13 (GND_4), P1.1, P1.2, P2.6, P2.7, P5.4, R5.1, SW1.2, U1.16 (VSS), U1.31 (VSSA), U1.38 (VSS), U1.51 (VSS), U1.61 (VSS), U1.83 (VSS), U1.94 (VSS), U1.107 (VSS), U1.120 (*VSS), U1.130 (*VSS), U2.4 (GND), U3.1 (PGND), U3.4 (AGND), U3.5 (FB), U3.9 (PAD), U4.1 (PGND), U4.4 (AGND), U4.5 (FB), U4.9 (PAD), U5.2 (GND), U6.2 (GND), U10.B1 (~CK/~RFU), U10.B3 (VSS), U10.C1 (VSSQ), U10.E5 (VSSQ), U12.2 (GND); also elsewhere on the board
unnamed: C9.2, U1.9 (PC15-OSC32_OUT), Y1.1
unnamed: C10.1, U1.23 (PH0-OSC_IN), Y2.2
unnamed: C11.2, U1.8 (PC14-OSC32_IN), Y1.2
unnamed: C12.1, U1.24 (PH1-OSC_OUT), Y2.1
unnamed: C14.1, U1.71 (VCAP)
unnamed: C15.1, U1.106 (VCAP)
unnamed: D3.2 (A), R26.1
unnamed: D4.2 (A), R4.1
unnamed: J4.1 (DAT2), R31.2
unnamed: J4.2 (CD/DAT3), R30.2
unnamed: J4.8 (DAT1), R27.2
unnamed: L3.1, U3.7 (SW)
unnamed: L4.1, U4.7 (SW)
VBUS: C42.1, U5.1 (VDD), U5.3 (EN), U12.1 (OUT); also elsewhere on the board
VDDA: C7.1, C8.1, L1.2, U1.32 (VREF+), U1.33 (VDDA)

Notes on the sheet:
Shield for Arduino Mega Rev 3
Holes

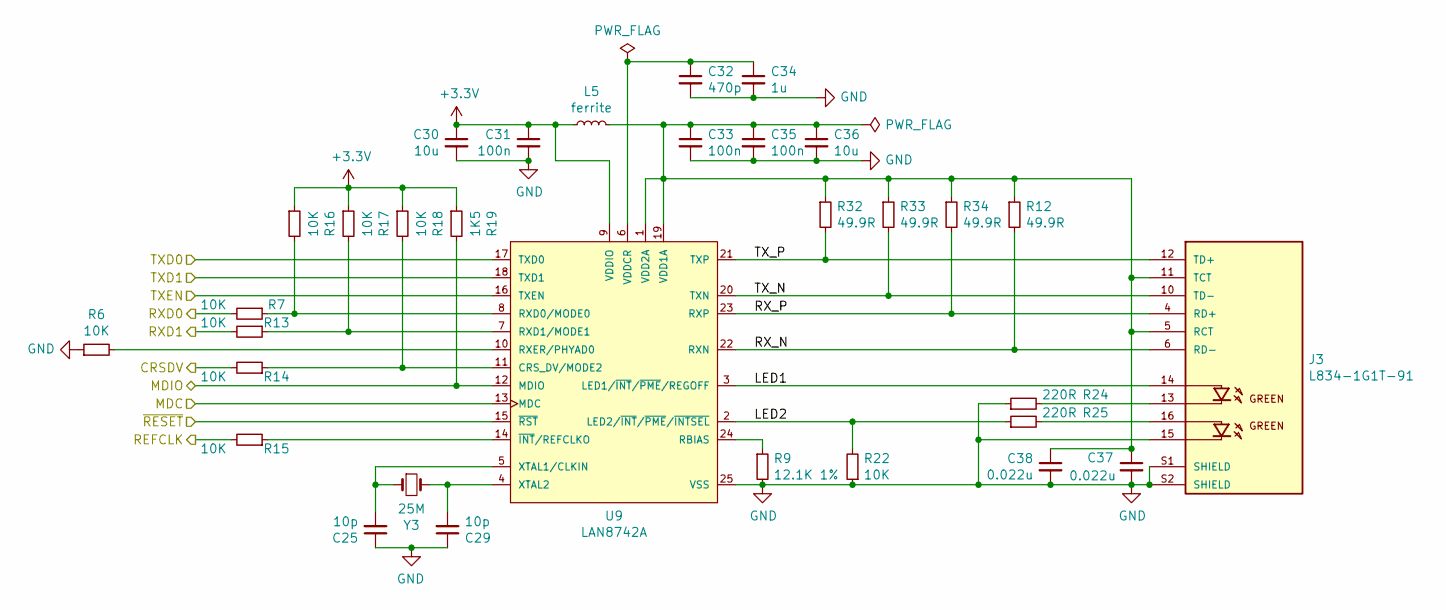
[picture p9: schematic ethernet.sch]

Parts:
C25, C29: 10p; C_0603_1608Metric; MANUFACTURER_PART_NUMBER CC0603JRNPO9BN100
C30, C36: 10u; C_0603_1608Metric; MANUFACTURER_PART_NUMBER 0603ZD106KAT2A
C31, C33, C35: 100n; C_0603_1608Metric; MANUFACTURER_PART_NUMBER CC0603KRX7R9BB104
C32: 470p; C_0603_1608Metric; MANUFACTURER_PART_NUMBER 06035C471KAT2A
C34: 1u; C_0603_1608Metric; MANUFACTURER_PART_NUMBER CC0603ZRY5V6BB105
C37, C38: 0.022u; C_0603_1608Metric; MANUFACTURER_PART_NUMBER 06035C223KAT2A
J3: L834-1G1T-91; BEL_L834-1G1T-91; PARTREV C
L5: ferrite; L_0603_1608Metric; MANUFACTURER_PART_NUMBER BK1608HS220-T
R6, R7, R13, R14, R15, R16, R17, R18, R22: 10K; R_0603_1608Metric; MANUFACTURER_PART_NUMBER RC0603FR-0710KL
R9: 12.1K 1%; R_0603_1608Metric; MANUFACTURER_PART_NUMBER RT0603BRD0712K1L
R12, R32, R33, R34: 49.9R; R_0603_1608Metric; MANUFACTURER_PART_NUMBER RC0603FR-0749R9L
R19: 1K5; R_0603_1608Metric; MANUFACTURER_PART_NUMBER RC0603JR-071K5L
R24, R25: 220R; R_0603_1608Metric; MANUFACTURER_PART_NUMBER RC0603JR-07220RL
U9: LAN8742A; Microchip-C04-143B-S4QFN-0-0-MFG; mouser part number 579-LAN8742A-CZ-TR; digikey description IC TRANSCEIVER 1/1 24SQFN
Y3: 25M; Crystal_SMD_5032-2Pin_5.0x3.2mm; MANUFACTURER_PART_NUMBER ABM7-25.000MHZ-D2Y-T

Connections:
+3V3: C30.1, C31.1, L5.1, R16.1, R17.1, R18.1, R19.1, U9.9 (VDDIO); also elsewhere on the board
/ETH_CRS_DV: R14.2; also elsewhere on the board
/ETH_MDC: U9.13 (MDC); also elsewhere on the board
/ETH_MDIO: R19.2, U9.12 (MDIO); also elsewhere on the board
/ETH_REF_CLK: R15.2; also elsewhere on the board
/ETH_RXD0: R7.2; also elsewhere on the board
/ETH_RXD1: R13.2; also elsewhere on the board
/ETH_TXD0: U9.17 (TXD0); also elsewhere on the board
/ETH_TXD1: U9.18 (TXD1); also elsewhere on the board
/ETH_TX_EN: U9.16 (TXEN); also elsewhere on the board
/Ethernet/LED1: J3.14, U9.3 (LED1/~INT~/~PME~/REGOFF)
/Ethernet/LED2: R22.2, R25.1, U9.2 (LED2/~INT~/~PME~/~INTSEL~)
/Ethernet/RX_N: J3.6 (RD-), R12.2, U9.22 (RXN)
/Ethernet/RX_P: J3.4 (RD+), R34.2, U9.23 (RXP)
/Ethernet/TX_N: J3.10 (TD-), R33.2, U9.20 (TXN)
/Ethernet/TX_P: J3.12 (TD+), R32.2, U9.21 (TXP)
/~ETH_RST: U9.15 (~RST~); also elsewhere on the board
GND: C25.1, C29.1, C30.2, C31.2, C32.2, C33.2, C34.2, C35.2, C36.2, C37.2, C38.2, J3.15, J3.S1 (SHIELD), J3.S2 (SHIELD), R6.1, R9.2, R22.1, R24.1, U9.25 (VSS); also elsewhere on the board
unnamed: C25.2, U9.5 (XTAL1/CLKIN), Y3.1
unnamed: C29.2, U9.4 (XTAL2), Y3.2
unnamed: C32.1, C34.1, U9.6 (VDDCR)
unnamed: C33.1, C35.1, C36.1, C37.1, C38.1, J3.5 (RCT), J3.11 (TCT), L5.2, R12.1, R32.1, R33.1, R34.1, U9.1 (VDD2A), U9.19 (VDD1A)
unnamed: J3.13, R24.2
unnamed: J3.16, R25.2
unnamed: R6.2, U9.10 (RXER/PHYAD0)
unnamed: R9.1, U9.24 (RBIAS)
unnamed: R13.1, R17.2, U9.7 (RXD1/MODE1)
unnamed: R14.1, R18.2, U9.11 (CRS_DV/MODE2)
unnamed: R15.1, U9.14 (~INT~/REFCLKO)
unnamed: R7.1, R16.2, U9.8 (RXD0/MODE0)

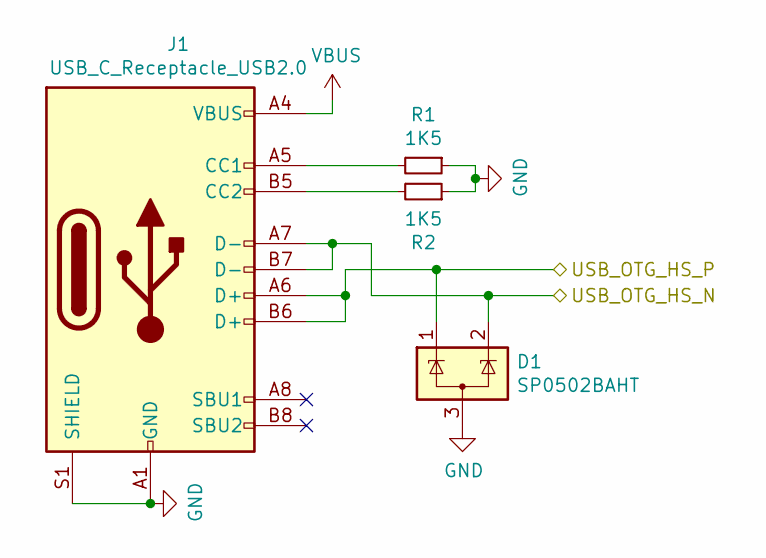
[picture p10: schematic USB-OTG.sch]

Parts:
D1: SP0502BAHT; SOT-23; MANUFACTURER_PART_NUMBER SP0502BAHTG
J1: USB_C_Receptacle_USB2.0; USB_C_Receptacle_Amphenol_12401610E4-2A; MANUFACTURER_PART_NUMBER 12401610E4-2A
R1, R2: 1K5; R_0603_1608Metric; MANUFACTURER_PART_NUMBER RC0603JR-071K5L

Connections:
/USB_OTG_HS_N: D1.2 (K), J1.A7 (D-), J1.B7 (D-); also elsewhere on the board
/USB_OTG_HS_P: D1.1 (K), J1.A6 (D+), J1.B6 (D+); also elsewhere on the board
GND: D1.3 (A), J1.A1 (GND), J1.A12 (GND), J1.B1 (GND), J1.B12 (GND), J1.S1 (SHIELD), R1.1, R2.1; also elsewhere on the board
unnamed: J1.A5 (CC1), R1.2
unnamed: J1.B5 (CC2), R2.2
VBUS: J1.A4 (VBUS), J1.A9 (VBUS), J1.B4 (VBUS), J1.B9 (VBUS); also elsewhere on the board

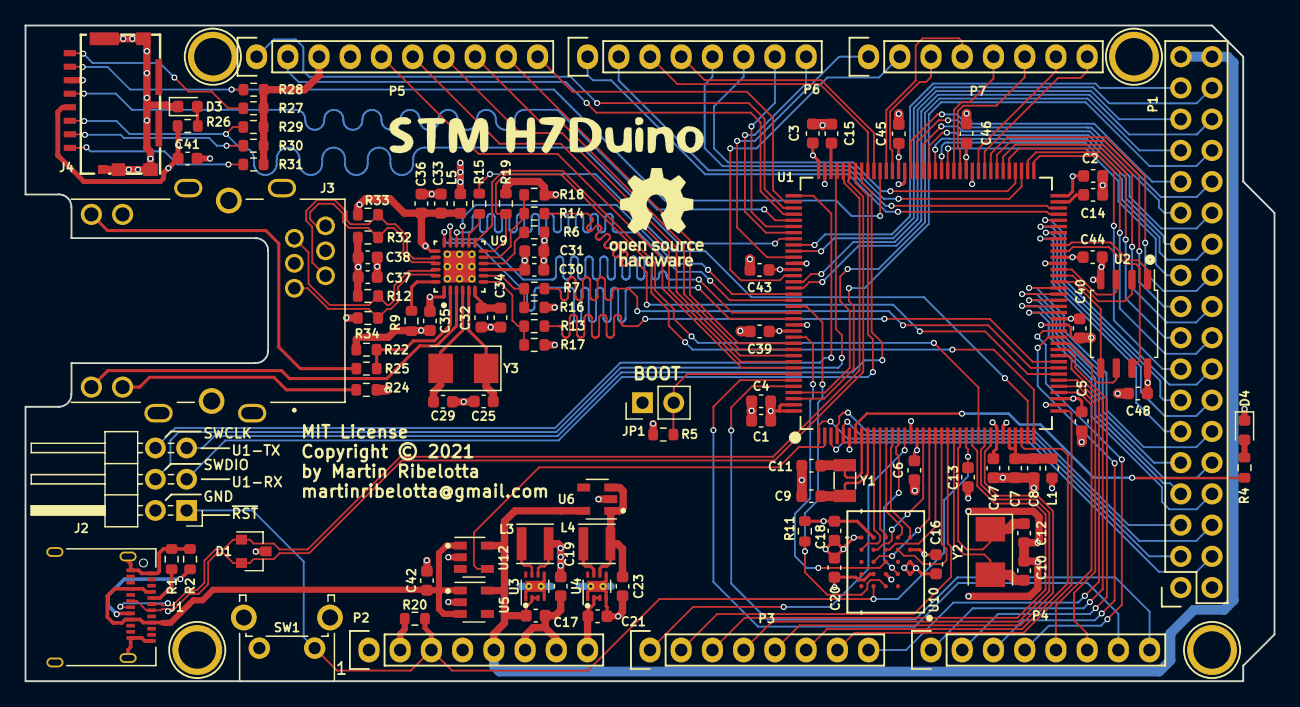
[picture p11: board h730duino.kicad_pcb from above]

Board: 4 copper layers, 101.6 x 53.3 mm, 111 parts (1 on the bottom side), 152 nets.

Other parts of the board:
QR1: https://github.com/martinribelotta/h730duino; url_qr

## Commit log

2021-02-19 Add gerbers
    [h730duino-B_Cu.gbr, h730duino-B_Mask.gbr, h730duino-B_SilkS.gbr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]
2021-02-21 Add SWD connector for cortex-m7, SWD poggo pins and boot jumper for cmsis-dap mcu.
    [debugger.sch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]
2021-02-21 Replace non stocked components.
    - Redesign 5V/3.3V using TPS6216xDSGT
    - Use bigger crystal (move to 5031 case)
    - Change some components parts
    [USB-OTG.sch, debugger.sch, ethernet.sch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]
2021-02-21 Add octopart BOM and update README.md
    [octopart-20210221_h730_duino.csv]
2021-02-22 Reorder power supply
    [h730duino-B_Cu.gbr, h730duino-B_Mask.gbr, h730duino-B_SilkS.gbr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]
2021-03-20 Fix in design:
    - Add r-series to QSPI interfaces
    - Change vCAP from 100n to 2.2u
    - Add pullup to SWCK/DIO and nRST
    - Remove AGND/DGND separation
    [debugger.sch, h730duino.kicad_pcb, h730duino.sch]
2021-03-20 Major rework:
    - Split flash/ram in two QSPI iface
    - Flash is connected to QSPI2
    - PSRAM is connected to QSPI1
    - Move QSPI PSRAM near to P1
    - Reorder pins to P1 and P5
    - Reasign I2C5, UART4 to more convenient place
    - Reasign PWM pins to more convenient place
    - Rerarrange 25MHz ETHPHY crystal
    [h730duino.kicad_pcb, h730duino.sch, pinout.csv]
2021-03-21 Improve previous changes:
    - Add pullup resistors to uSD card slot
    - Reroute some signals for more space
    - Check impedance of QSPI/USB signals
    - Match length of uSD signals
    [h730duino.kicad_pcb, h730duino.sch]
2021-03-22 Add new BOM to octopart
    TODO: PSRAM is not recognized by Octopart but is available in LCSC
    [20210322_stm32h73x_duino_csv.csv, USB-OTG.sch, debugger.sch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]
2021-03-22 Update schemas
    [ethernet.sch, h730duino.sch]
2021-03-24 Replace LAN8742 by KSZ8081RND/RNA
    [ethernet.sch, h730duino.kicad_pcb]
2021-03-24 Replace STM32F042 in TSSOP by STM32F04[28] in QFN28
    Others changes:
    - Export gerbers to current status
    - Update schematic export in svg and pdf
    - Update README image
    - Rename `USB OTG` sheet to `USB_OTG`
    [debugger.sch, ethernet.sch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]
2021-04-04 Save point
    [debugger.sch, ethernet.sch, h730duino.kicad_pcb]
2021-04-05 Change QSPI PSRAM to hyperRAM
    - Replace QSPI PSRAM to HyperBUS version due to erratasheet
    of mcu (cannot write in QSPI mode without DQS and DQS not
    work in 4bit mode)
    - Connect hyperram to QSPI interface 2
    - Move QSPI flash to interface 1
    - Rearrangue pinouts due to new functionality
    - Remove extra pinouts (now all pins are in arduino connector9
    - Improve schematic and libreries to pass ERC
    - Add pin-1 mark on all IC
    [debugger.sch, ethernet.sch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]
2021-04-17 Return to lan8742A in ETH PHY
    [ethernet.sch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]
2021-04-18 Prepare for send to PCBWay
    [debugger.sch, ethernet.sch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]
2021-04-18 Add BOM for PCBWay
    [BOM_PCBWay.xlsx]
2021-04-18 Add edge cut to gerbers
    [h730duino-B_Cu.gbr, h730duino-B_Mask.gbr, h730duino-B_SilkS.gbr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]
2021-04-19 Add PCBWay approved gerber files
2021-04-20 Add centroid position files to the gerbers
    [h730duino-bottom-pos.csv, h730duino-top-pos.csv]
2021-07-31 Fix 1V8 issue and OSPI pinout
    [debugger.sch, h730duino.kicad_pcb, h730duino.sch]
2021-07-31 REally fix HyperRAM connection.
    Additionally:
    - Fix PTH on ETH connector
    - Move USB-C to the left
    [h730duino.kicad_pcb, h730duino.sch]
2021-07-31 Change 1V8 regulator for a more cheap and small part
    [debugger.sch, h730duino.kicad_pcb]
2021-08-03 Some changes
    [h730duino.kicad_pcb]
2021-08-16 Add QR of project URL
    [USB-OTG.sch, ethernet.sch, h730duino.kicad_pcb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]

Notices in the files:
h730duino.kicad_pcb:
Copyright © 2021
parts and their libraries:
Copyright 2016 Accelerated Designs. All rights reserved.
